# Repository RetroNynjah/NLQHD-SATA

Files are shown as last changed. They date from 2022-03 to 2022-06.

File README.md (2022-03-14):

# RetroNinja NLQHD-SATA
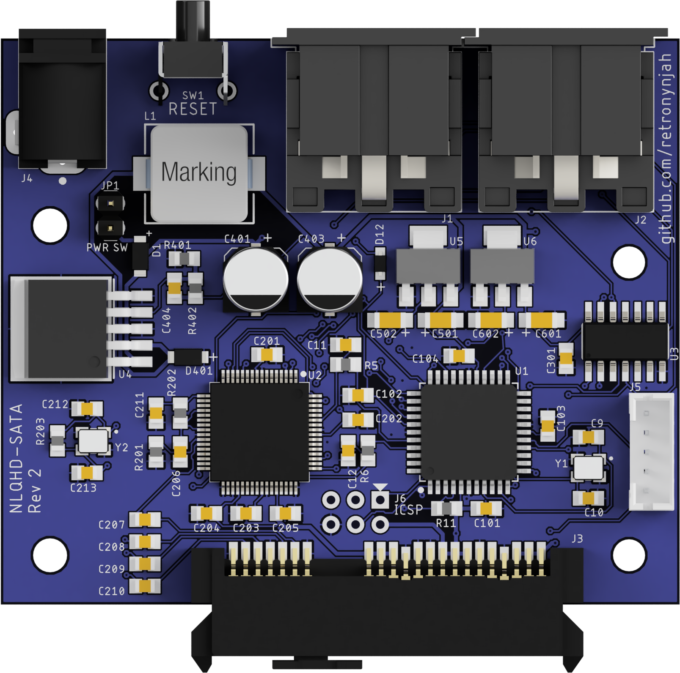
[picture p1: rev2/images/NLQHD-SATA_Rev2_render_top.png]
Render top
<br/>

A SATA-disk interface for the Commodore IEC-bus based on the NLQHD-lite design by Jochen Adler a.k.a. NLQ. The original design, documentation, firmware and source code can be found at [nlq.de](http://nlq.de).

## NLQ-HD
The NLQHD disk interface is a JiffyDOS compatible hard disk controller for the IEC bus. It was designed by Jochen Adler who also wrote the firmware. It supports a partition size of up to 128GB. Larger hard drives can be used but the partition size can not be greater than 128GB. 
The file system used is FAT32 so with a SATA-USB adapter it's easy to unplug and connect the SATA drive to a computer for quick file transfers.  
It should work with all Commodore 8-bit computers using an IEC bus. The drive can in theory be used with a stock kernal in the computer but the standard commands for navigating directories uses the command channel and are pretty cumbersome to use. A JiffyDOS kernal or one of it's derivatives such as S-JiffyDOS or JaffyDOS is pretty much required.

## NLQHD-SATA
This SATA version is a somewhat simplified design in that it doesn't have the same level of over-voltage protection as the original design has. The reason is that I wanted to keep the size of the design down (70x58mm) to fit in a 3D-printed enclosure. It also can't be powered by 1541-II PSU so the protection is less necessary than on the original design. I recommend that this version is powered using a decent quality 12V DC adapter with a center positive barrel connector.  
I have also removed the debugging/programming dip switches so the programming software for the C64 can't be used for flashing the firmware. I don't think it's safe to use so don't even try to use it!  
Instead I have added an ICSP programming header so that the firmware can be programmed in circuit using any AVR programmer such as AVR-ISP, USBASP or even an Arduino (Arduino as ISP). More importantly I've also added a JMH330 PATA-SATA bridge so that the interface can be used with more available and reliable SSD drives without an extra adapter. All SATA drives should be possible to use, from older 3.5" rotational drives to the newer 2.5" SSD drives. 
I replaced the sometimes hard-to-find 5 Volt regulator with integrated components based around an LM2596 voltage regulator. These have unfortunately also became harder to find from reliable sources at the time of writing but are easy to find on eBay or AliExpress. 3.3V and 1.8V voltage regulators have been added to drive the SATA bridge.  
I have made a separate front panel for the control buttons and LEDs. It connects to the mainboard using a 5 pin connector and can easily be replaced by a different panel if you need a different shape.  

<br/>
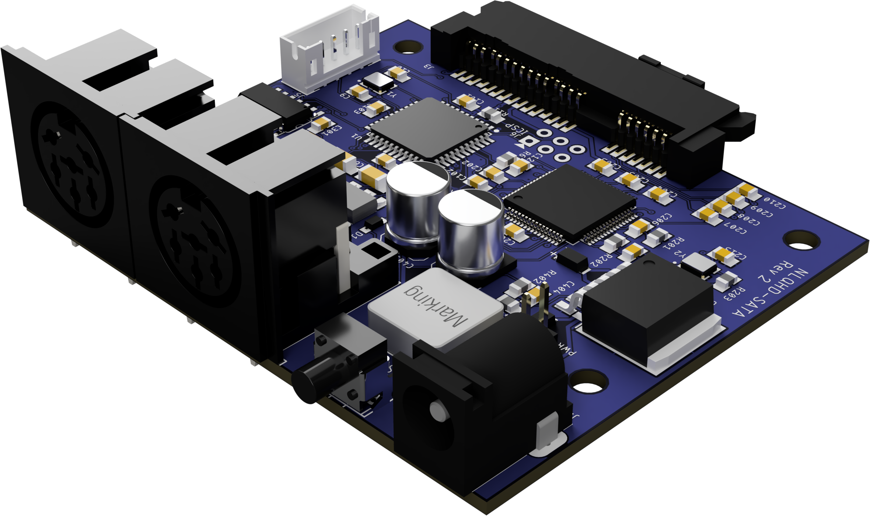
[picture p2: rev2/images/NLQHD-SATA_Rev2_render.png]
Render top
<br/>

I have also created a simple front panel board with buttons and status LEDs.  
This separate board should be pretty easy to modify to suite your own needs.
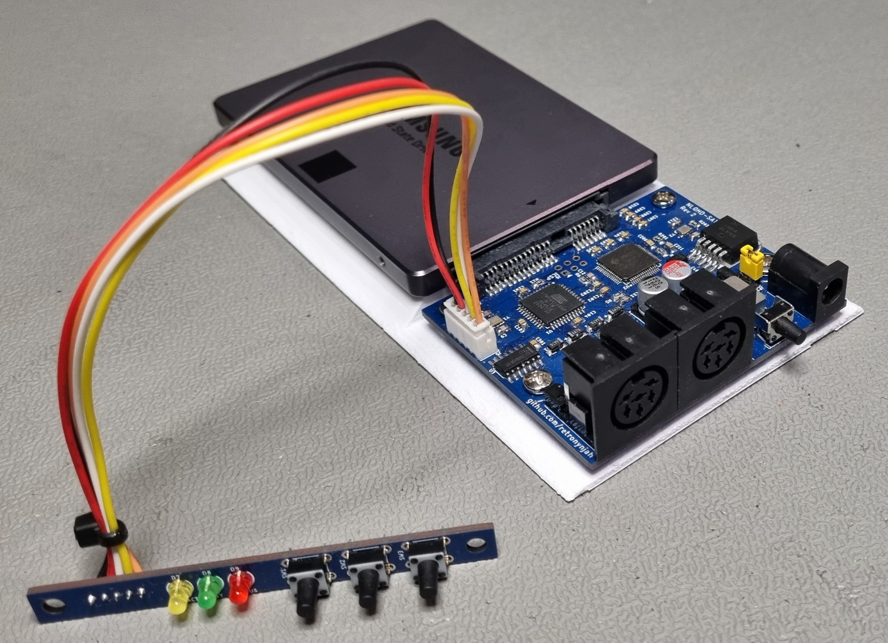
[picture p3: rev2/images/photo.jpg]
<br/>

## Mainboard BOM

|Parts|Device|Value|Qty|
|-----|-----|-----|-----|
|C101, C102, C103, C104, C201, C202, C203, C204, C205, C206, C301|Ceramic capacitor 0805|100n|11|
|C11, C12|Ceramic capacitor 0805|100p|2|
|C207, C208, C209, C210|Ceramic capacitor 0805|10n|4|
|C211|Ceramic capacitor 0805|1u 10V|1|
|C401|Electrolytic capacitor SMD 6.3X7.7|100u 25V|1|
|C403|Electrolytic capacitor SMD 6.3X7.7|220u 10V|1|
|C404|Ceramic capacitor 0805|10n(*)|1|
|C501, C502, C601, C602|Polarized tantalum capacitor 1206|10uF 10V|4|
|C9, C10, C212, C213|Ceramic capacitor 0805|22p|4|
|D1, D401|Schottky diode 3A SOD-123FL|S34|2|
|D12|General purpose diode SOD-323F|1N4148WSF|1|
|J1, J2|DIN-6 Female PCB-mount||2|
|J3|Molex 22-pin SATA host connector|0470184000|1|
|J4|DC Barrel Jack|PJ-002A|1|
|J5|Shrouded male JST header|5-pin, 2.0mm|1|
|J6|Pin header|2x3-pin, 2.54mm|1|
|JP1|Jumper or power switch|2-pin, 2.54mm|1|
|L1|Inductor 10x11mm|33uH|1|
|R11|Resistor 0805|10k|1|
|R201|Resistor 0805|12k|1|
|R202|Resistor 0805|47k|1|
|R203|Resistor 0805|1M|1|
|R401|Resistor 0805|1k (*)|1|
|R402|Resistor 0805|3k1/0R(*)|1|
|R5, R6|Resistor 0805|100R|2|
|SW1|Tact. switch right angle|6.0x5.0x8.5mm|1|
|U1|Microcontroller TQFP-44|ATmega1284(P)|1|
|U2|PATA-SATA bridge TQFP-64|JMH330|1|
|U3|Hex buffers/drivers SOIC14|74LS07|1|
|U4|Switching regulator TO263-5|LM2596 (AP1501A)|1|
|U5|Volt regulator 3.3V SOT-223|LD1117-3.3|1|
|U6|Volt regulator 1.8V SOT-223|LD1117-1.8|1|
|Y1|Crystal ECX-32|8MHz|1|
|Y2|Crystal ECX-32|25MHz|1|

(*) Only for Adjustable LM2596.
If using a fixed 5V LM2596: Do NOT install R401 and C404 and use a 0 Ohm resistor at R402

There are several variants of 6-pin DIN connectors with different foot prints. I have tried to accommodate them all in one single foot print. Let me know if you have a DIN connector that still doesn't fit this board.

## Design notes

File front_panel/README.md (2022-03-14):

A front panel for the NLQHD-SATA

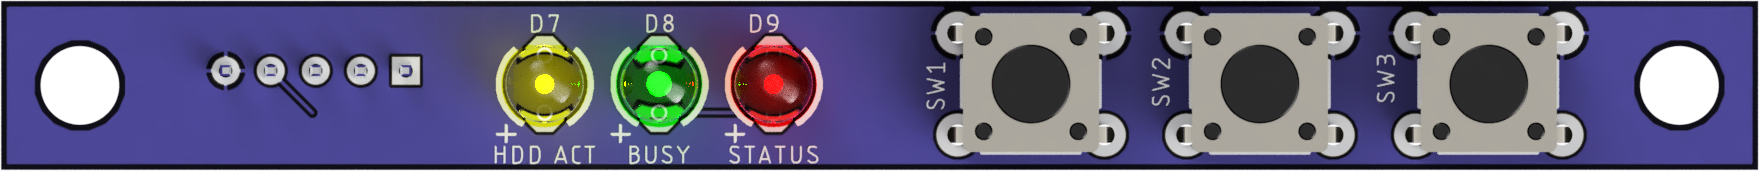
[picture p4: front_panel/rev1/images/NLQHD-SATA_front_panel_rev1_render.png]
Render
<br/>

## BOM
|Parts|Device|Value|Qty|
|-----|-----|-----|-----|
|SW2, SW3|Tact switch|6.0x6.0x9.0mm|2|
|D7|3mm LED|Yellow|1|
|D8|3mm LED|Green|1|
|D9|3mm LED|Red|1|
|D2, D3|General purpose diode SOD-323F|1N4148WSF|2|
|R7, R8, R9|Resistor 0805|560R|3|

Choose resistors that work with the actual LEDs you have on hand. Many super bright LEDs need a lot more resistance to not be blindingly bright.

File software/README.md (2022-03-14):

This folder contains is the original software, firmware and sourece code created by Jochen Adler (NLQ). All rights belongs to him.  
The same package is available from http://nlq.de. I'm only keeping a copy here for convenience.

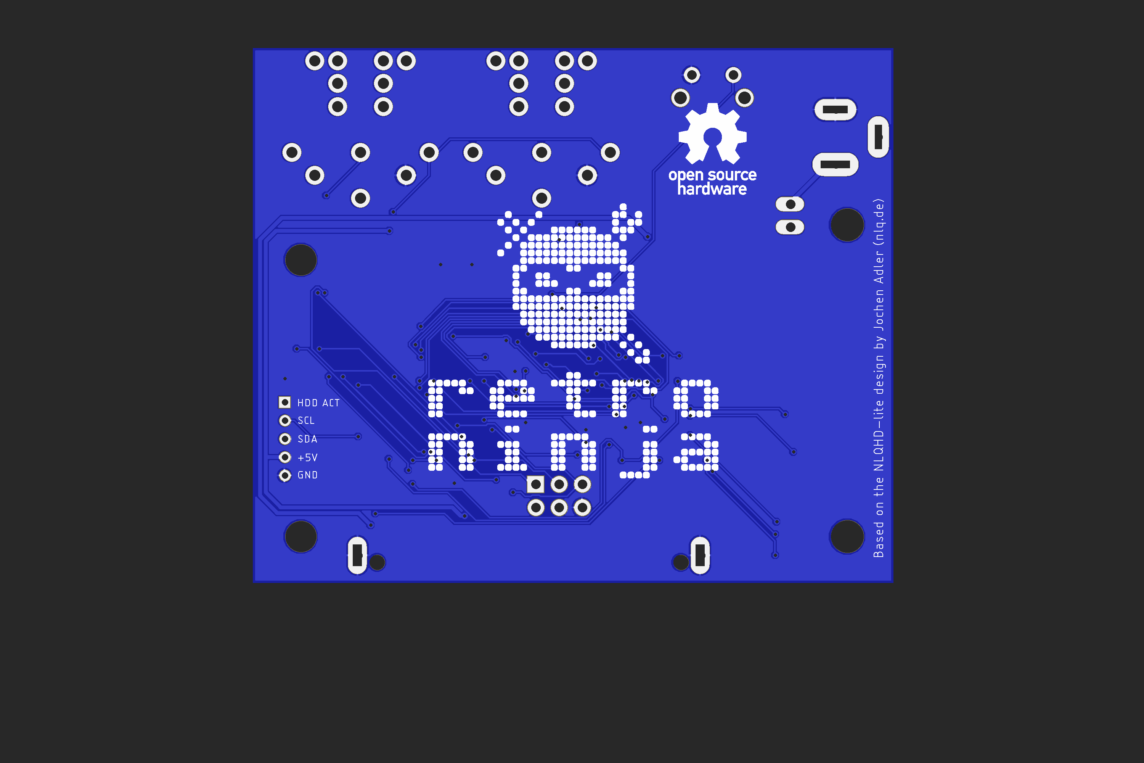
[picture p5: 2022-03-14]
rev2/images/NLQHD-SATA Rev 2 pcb bottom.png

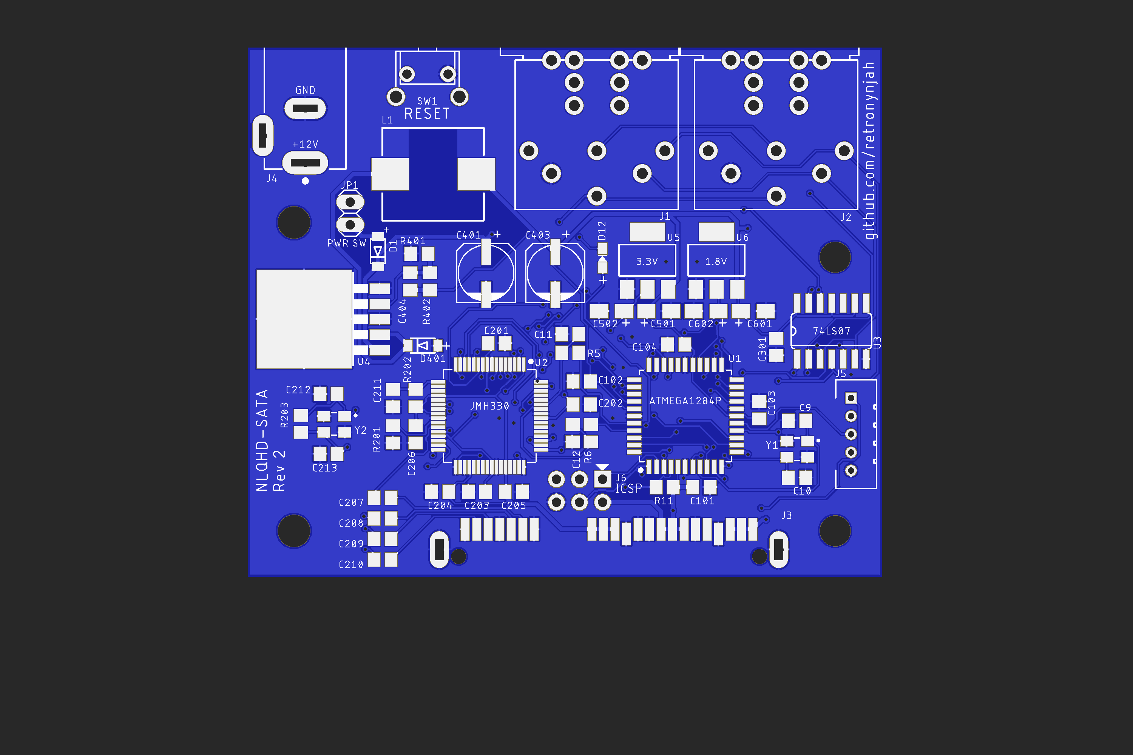
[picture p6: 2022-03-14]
rev2/images/NLQHD-SATA Rev 2 pcb top.png

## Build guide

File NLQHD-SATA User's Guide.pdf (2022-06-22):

# NLQHD-SATA

# User's Guide

### Version 1.1

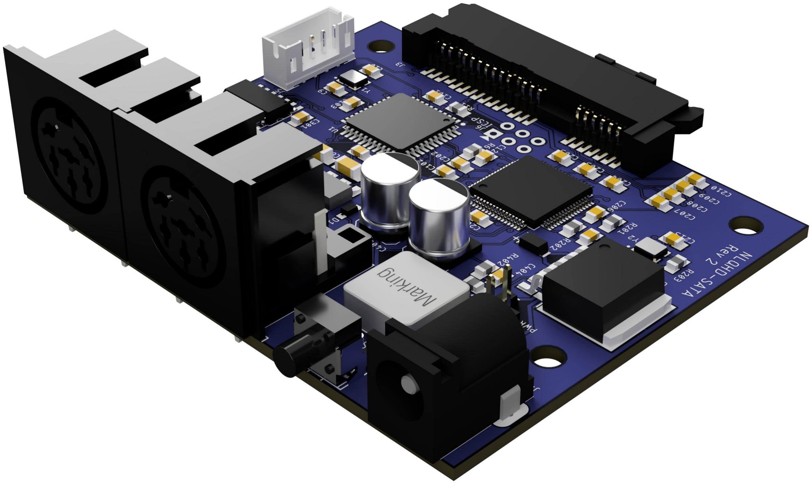
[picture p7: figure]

## Table of Contents

## Getting started

## Assembly

I suggest that you start the build by adding the LM2596 regulator and all it's peripheral components (see the area around the LM2596 in the schematic) and verify that you can power the PCB with 12V and get 5V out from the regulator. If you make a mistake here there's a good chance that the regulator outputs 12V and that would fry other components on the board if they were installed. You should have 5V on both sides of the inductor L1 when everything is right.
Because of component shortages ,the PCB is made to support a couple of different 5V regulators – a fixed 5V LM2596 regulator or the cheaper adjustable LM2596 which requires a couple of extra peripheral components (R401 and C404) and a 3.1kΩ resistor at R402 to keep the voltage at 5V.
If you go with a fixed 5V regulator your should not mount R401 and C404 and you should install a 0Ω resistor or a little jumper wire instead of a resistor at R402.
When you have an acceptable 5V output, add the 3.3V and 1.8V regulators and capacitors C501, C502, C601, C602 and verify the 1.8V and 3.3V by measuring the center pin on each regulator.
When all voltages are verified you can add the rest of the SMD parts including the SATA connector and then the through-hole parts.

### Supplying power

The controller needs to be powered by 12V DC through a barrel jack with +12V on the center pin or by soldering wires to the foot print where the barrel jack would be.
For SSD drives, a 1A power supply should be more than enough but it might be a bit on the low side for a 3.5" 7200 RPM disk so a 2A PSU might be a safer choice in that case.
The jumper JP1 can be used to install a power switch, a header and jumper or a permanent solder jumper. Opening the jumper removes all power to the board.

## Flashing the firmware

The firmware to program the ATmega with is named nh4lite0.bin and can be found in the ajnnh057.zip archive under software in the NLQHD-SATA GitHub repository at https://github.com/RetroNynjah/NLQHD-SATA (https://github.com/RetroNynjah/NLQHD-SATA) or at http://nlq.de
The following AVR fuses should be used.
LFUSE | $FF
HFUSE | $D9
EFUSE | $FD

There are several ways to program an ATmega but the below example is using AVRDUDE.
Setting the fuses and flashing the firmware on an Atmega1284 at the same time can be done like this.

You will have to adjust the command to match your programmer and change your AVR device if you are using an Atmega1284P. The fuses are the same for 1284P.

avrdude -C avrdude.conf -v -p atmega1284 -c usbasp -U lfuse:w:0xff:m -U hfuse:w:0xd9:m -U efuse:w:0xfd:m -Uflash:w:nh4lite0.bin

## Configuring the interface

The device configuration is stored in the EEPROM of the ATmega1284 and needs to be set after programming the firmware. To configure the device, connect it to a C64 or C128 and run the configuration program.
The configuration program can be found on the nlqhd-057-lite.d64 and nlqhd-057-lite.d81 disks.
The program is called C-NLQ-CAL&CON271
When asked if you are using NLQHD-lite hardware the answer is Yes.
Go through the configuration wizard and choose to configure each option. The default choices are usually fine but you may want to select a device ID that suits your environment.
When you are back at the configuration menu, select M to copy messages to the Atmega1284 EEPROM. This transfer status message texts and drive identification string to the EEPROM. Without this the drive will not report any text along with the error codes when querying the drive error channel for status and it won't present itself properly if you query the error channel directly after drive reset. You can use the @ command to query the drive error channel from JiffyDOS to make sure that it's reporting status correctly.
You don't need to run any calibration with the NLQHD-SATA because it is using an external crystal and therefore it's also not a problem to use JiffyDOS while configuring the device despite the warnings in the configuration program that speeders should be disabled until the oscillator has been calibrated.

## Formatting the disk

You can use the program C-NLQ-PAR&FOR232 to partition and format your disk using FAT32 if it's not already partitioned and formatted. Using this tool for partitioning a larger disk ensures that the partition size is exactly the maximum supported size.

## Using your hard drive

## Disk commands

The below command examples assumes JiffyDOS kernal on the computer.
To issue the commands without JiffyDOS you would have to use a command like OPEN15,8,15,”CD:GAMES” instead of just @CD:GAMES.

### Changing directories

Move to directory

Go up one directory level

Go back to the root directory

All commands that target file or folder names that includes spaces must be within quotes. Examples:
Move to directory

### Adding and removing files and directories

Create new directory

Remove directory (must be empty)

Delete (scratch) a file

Delete (scratch) all files in current directory with names beginning with MY

Delete (scratch) all files in current directory

@CD:GAMES

@CD//

@CD<= (PETSCII left arrow)

@”CD:MY GAMES”

@”RD:MY OLD DIR”

@”S:MY OLD FILE”

@”S:MY*”

@S:*

@”MD:MY APPS”

### Renaming files and directories

Rename a file or directory

### Misc commands

Turn off device (press reset switch to wake up again)

## Other functions

### Swapping ID

It's possible to temporarily swap device ID with another device that has device ID 8 or 9.
This makes it possible to run software that assumes that a disk drive must have ID 8 or 9.
To swap ID, press the middle button (left button if there are only two buttons) eight times. The busy light will start flashing series of eight flashes. Now press the right button to execute the device change.
Pressing the middle button nine times followed by a right button press swaps ID with device 9.
Example: The NLQHD is device 30 and a 1541 disk drive is device 8. After the ID swap the 1541 is device 30 and the NLQHD is device 8.
The NLQHD can now be used as if the current folder was a disk inserted into device 8.

### Standby mode

The device can be put into standby by holding the right button for 4 seconds or more. When the device is in standby it's device ID is removed from the IEC bus and can be used by other devices.
To wake the device from standby you can press the middle button on the front panel or the reset button at the back of the interface.

## Resources

NLQHD-SATA GitHub repository https://github.com/RetroNynjah/NLQHD-SATA NLQ web site
http://nlq.de
JiffyDOS web site
http://www.jiffydos.com

@”R:NEW FILENAME=OLD FILENAME”

@AOF

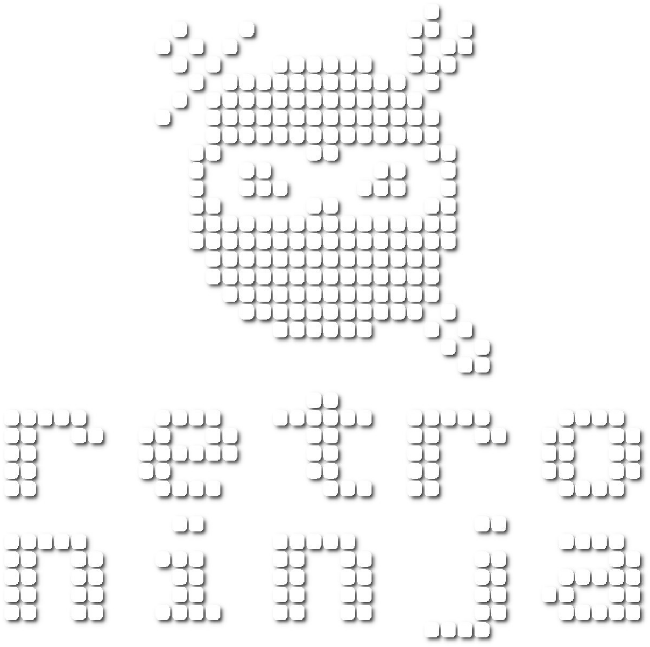
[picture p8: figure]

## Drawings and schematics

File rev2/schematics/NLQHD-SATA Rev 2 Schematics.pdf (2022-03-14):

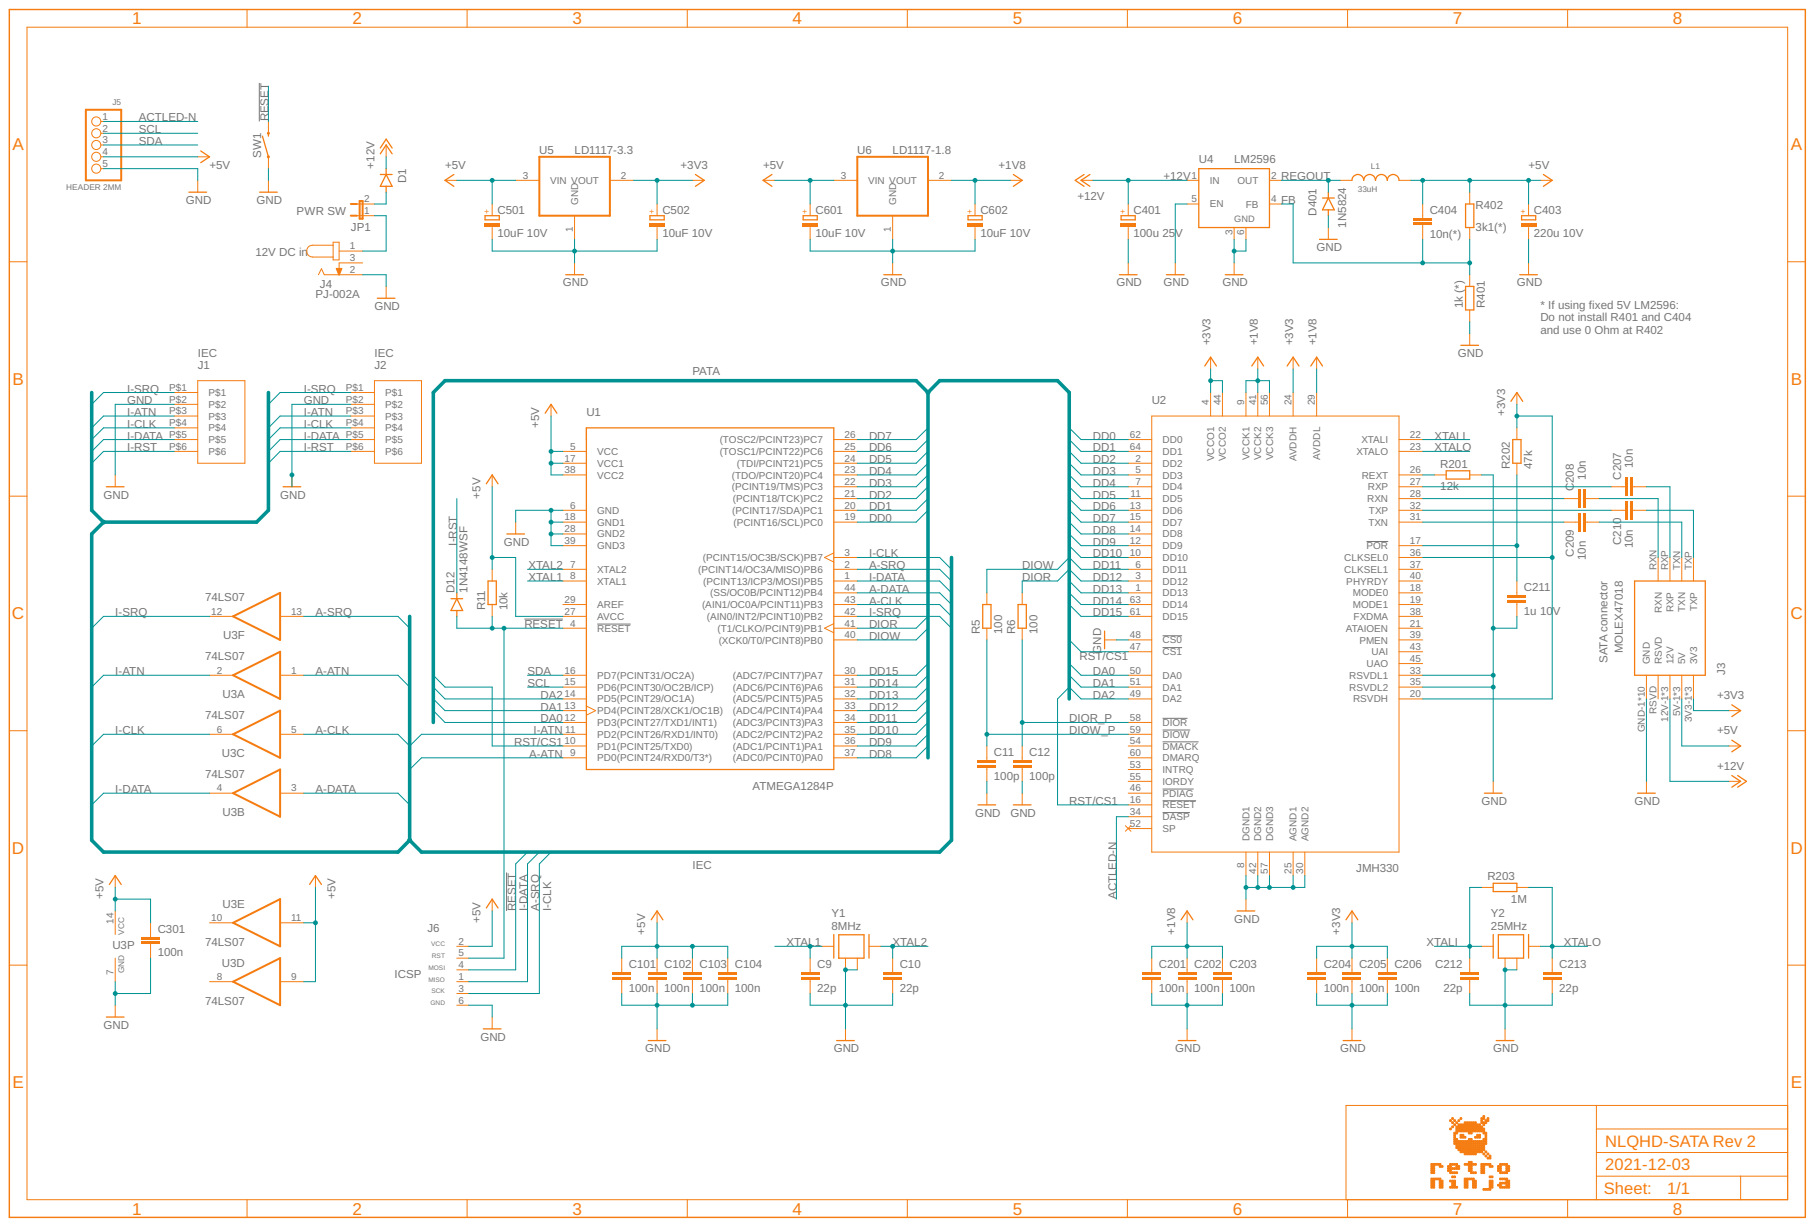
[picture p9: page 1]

* If using fixed 5V LM2596: Do not install R401 and C404

and use 0 Ohm at R402

SCK RST VCC MOSI GND

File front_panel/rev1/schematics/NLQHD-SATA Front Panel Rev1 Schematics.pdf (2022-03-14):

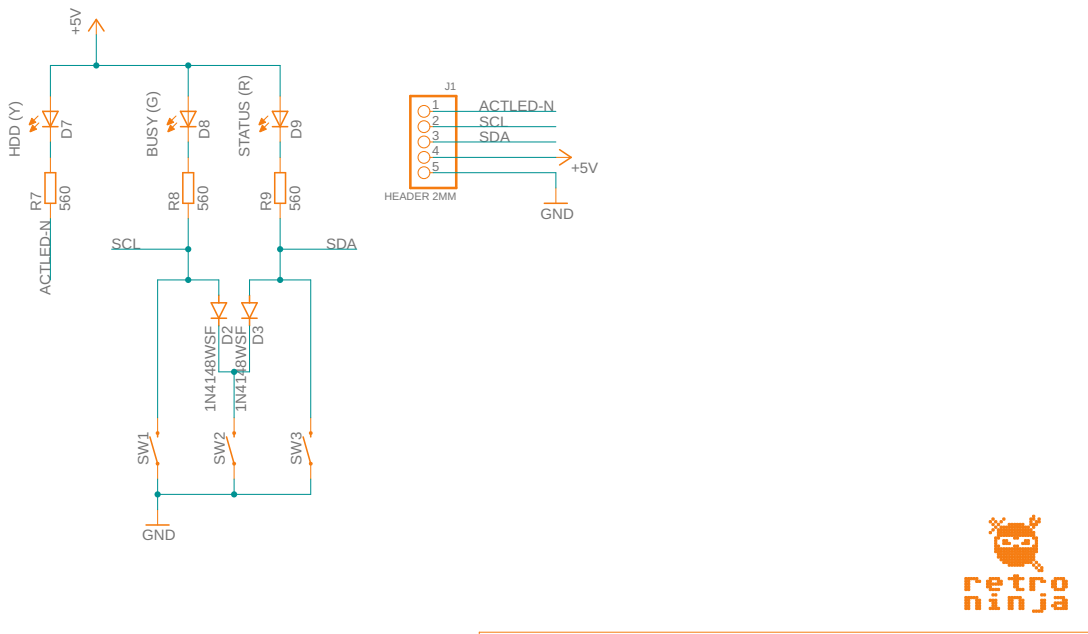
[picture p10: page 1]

NLQHD-SATA Front Panel Rev 1

Document Number: | REV: 1

Date: 2021-12-07 | Sheet: 1/1

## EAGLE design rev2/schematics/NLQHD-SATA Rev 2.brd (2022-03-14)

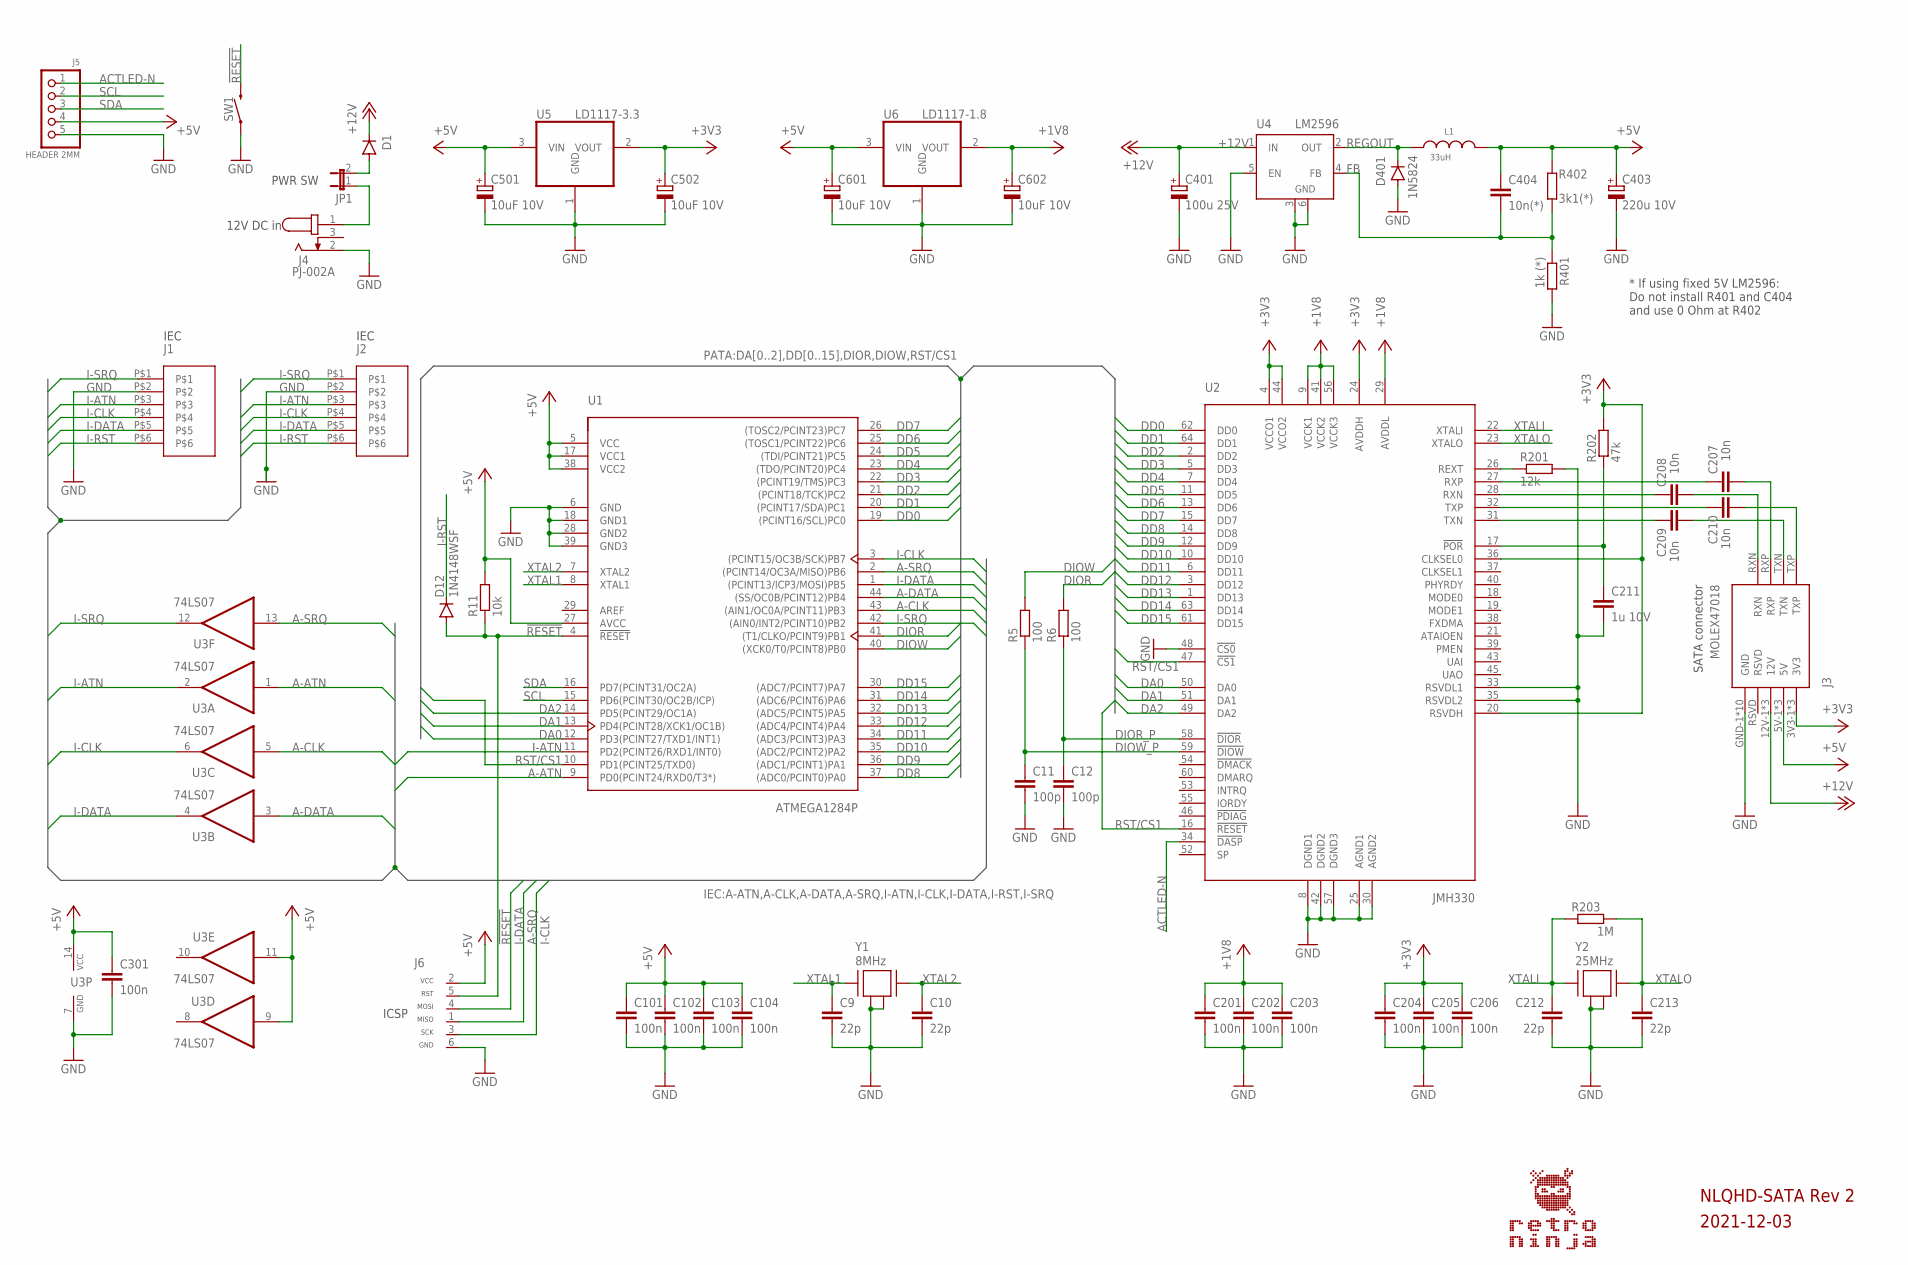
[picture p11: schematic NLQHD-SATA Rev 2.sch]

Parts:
C9, C10, C212, C213: 22p; C0805
C11, C12: 100p; C0805
C101, C102, C103, C104, C201, C202, C203, C204, C205, C206, C301: 100n; C0805
C207, C208, C209, C210: 10n; C0805
C211: 1u 10V; C0805
C401: 100u 25V; CAP_POL_SMD_6.3X7.7
C403: 220u 10V; CAP_POL_SMD_6.3X7.7
C404: 10n(*); C0805
C501, C502, C601, C602: 10uF 10V; A/3216-18R
D1: DIODE_SOD-123FL; SOD-123FL
D12: 1N4148WSF; SOD-323F
D401: 1N5824; SOD-123FL
J1, J2: DIN-6_PCB; DIN-6-PCB
J3: MOLEX47018; MOLEX47018SATA
J4: PJ-002A; CUI_PJ-002A
J5: HEADER 2MM; HEADER_1X5_2MM_JST
J6: ICSP_CONNECTOR_6_ALT; HEADER_2X3_ALT
JP1: JUMPER-2; HEADER_1X2
L1: 33uH; WE-LHMI_1040
R5, R6: 100; R0805
R11: 10k; R0805
R201: 12k; R0805
R202: 47k; R0805
R203: 1M; R0805
R401: 1k (*); R0805
R402: 3k1(*); R0805
SW1: SWITCH_MOMENTARY_6.0X5.0_RIGHT_ANGLE; SWITCH_MOM_6.0MMX5.0MM_RIGHT_ANGLE
U1: ATMEGA1284P; TQFP-44
U2: JMH330; TQFP-64_12X12X1.20
U3: 74LS07; SOIC14
U4: LM2596; TO263-5
U5: LD1117-3.3; SOT223
U6: LD1117-1.8; SOT223
Y1: 8MHz; ECX-32
Y2: 25MHz; ECX-32

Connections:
!POR: C211.1, R202.1, U2.17 (!POR)
!RESET: D12.A, J6.5 (RST), R11.1, SW1.2, U1.4 (!RESET)
+1V8: C201.1, C202.1, C203.1, C602.+, U2.9 (VCCK1), U2.29 (AVDDL), U2.41 (VCCK2), U2.56 (VCCK3), U6.2 (VOUT)
+3V3: C204.1, C205.1, C206.1, C502.+, J3.3V3-1 (3V3), J3.3V3-2 (3V3), J3.3V3-3 (3V3), R202.2, U2.4 (VCCO1), U2.20 (RSVDH), U2.24 (AVDDH), U2.36 (CLKSEL0), U2.44 (VCCO2), U5.2 (VOUT)
+5V: C101.1, C102.1, C103.1, C104.1, C301.1, C403.+, C404.1, C501.+, C601.+, J3.5V-1 (5V), J3.5V-2 (5V), J3.5V-3 (5V), J5.4, J6.2 (VCC), L1.2, R11.2, R402.2, U1.5 (VCC), U1.17 (VCC1), U1.27 (AVCC), U1.38 (VCC2), U3.9 (I), U3.11 (I), U3.14 (VCC), U5.3 (VIN), U6.3 (VIN)
+12V: C401.+, D1.C, J3.12V-1 (12V), J3.12V-2 (12V), J3.12V-3 (12V), U4.1 (IN)
+12V-IN: J4.1, JP1.1
A-ATN: U1.9 (PD0(PCINT24/RXD0/T3*)), U3.1 (I)
A-CLK: U1.43 ((AIN1/OC0A/PCINT11)PB3), U3.5 (I)
A-DATA: U1.44 ((SS/OC0B/PCINT12)PB4), U3.3 (I)
A-SRQ: J6.1 (MISO), U1.2 ((PCINT14/OC3A/MISO)PB6), U3.13 (I)
ACTLED-N: J5.1, U2.34 (!DASP)
DA0: U1.12 (PD3(PCINT27/TXD1/INT1)), U2.50 (DA0)
DA1: U1.13 (PD4(PCINT28/XCK1/OC1B)), U2.51 (DA1)
DA2: U1.14 (PD5(PCINT29/OC1A)), U2.49 (DA2)
DD0: U1.19 ((PCINT16/SCL)PC0), U2.62 (DD0)
DD1: U1.20 ((PCINT17/SDA)PC1), U2.64 (DD1)
DD2: U1.21 ((PCINT18/TCK)PC2), U2.2 (DD2)
DD3: U1.22 ((PCINT19/TMS)PC3), U2.5 (DD3)
DD4: U1.23 ((TDO/PCINT20)PC4), U2.7 (DD4)
DD5: U1.24 ((TDI/PCINT21)PC5), U2.11 (DD5)
DD6: U1.25 ((TOSC1/PCINT22)PC6), U2.13 (DD6)
DD7: U1.26 ((TOSC2/PCINT23)PC7), U2.15 (DD7)
DD8: U1.37 ((ADC0/PCINT0)PA0), U2.14 (DD8)
DD9: U1.36 ((ADC1/PCINT1)PA1), U2.12 (DD9)
DD10: U1.35 ((ADC2/PCINT2)PA2), U2.10 (DD10)
DD11: U1.34 ((ADC3/PCINT3)PA3), U2.6 (DD11)
DD12: U1.33 ((ADC4/PCINT4)PA4), U2.3 (DD12)
DD13: U1.32 ((ADC5/PCINT5)PA5), U2.1 (DD13)
DD14: U1.31 ((ADC6/PCINT6)PA6), U2.63 (DD14)
DD15: U1.30 ((ADC7/PCINT7)PA7), U2.61 (DD15)
DIOR: R6.2, U1.41 ((T1/CLKO/PCINT9)PB1)
DIOR_P: C12.1, R6.1, U2.58 (!DIOR)
DIOW: R5.2, U1.40 ((XCK0/T0/PCINT8)PB0)
DIOW_P: C11.1, R5.1, U2.59 (!DIOW)
FB: C404.2, R401.1, R402.1, U4.4 (FB)
GND: C9.2, C10.2, C11.2, C12.2, C101.2, C102.2, C103.2, C104.2, C201.2, C202.2, C203.2, C204.2, C205.2, C206.2, C211.2, C212.2, C213.2, C301.2, C401.-, C403.-, C501.-, C502.-, C601.-, C602.-, D401.A, J1.P$2, J2.P$2, J3.GND-1 (GND), J3.GND-2 (GND), J3.GND-3 (GND), J3.GND-4 (GND), J3.GND-5 (GND), J3.GND-6 (GND), J3.GND-7 (GND), J3.GND-8 (GND), J3.GND-9 (GND), J3.GND-10 (GND), J4.2, J5.5, J6.6 (GND), R201.2, R401.2, SW1.1, U1.6 (GND), U1.18 (GND1), U1.28 (GND2), U1.39 (GND3), U2.8 (DGND1), U2.25 (AGND1), U2.30 (AGND2), U2.33 (RSVDL1), U2.35 (RSVDL2), U2.42 (DGND2), U2.48 (!CS0), U2.57 (DGND3), U3.7 (GND), U4.3 (GND), U4.5 (EN), U4.6 (GND), U5.1 (GND), U6.1 (GND), Y1.2, Y1.4, Y2.2, Y2.4
I-ATN: J1.P$3, J2.P$3, U1.11 (PD2(PCINT26/RXD1/INT0)), U3.2 (O)
I-CLK: J1.P$4, J2.P$4, J6.3 (SCK), U1.3 ((PCINT15/OC3B/SCK)PB7), U3.6 (O)
I-DATA: J1.P$5, J2.P$5, J6.4 (MOSI), U1.1 ((PCINT13/ICP3/MOSI)PB5), U3.4 (O)
I-RST: D12.C, J1.P$6, J2.P$6
I-SRQ: J1.P$1, J2.P$1, U1.42 ((AIN0/INT2/PCINT10)PB2), U3.12 (O)
unnamed: R201.1, U2.26 (REXT)
unnamed: D1.A, JP1.2
unnamed: C207.2, J3.RXP
unnamed: C208.2, J3.RXN
unnamed: C210.2, J3.TXP
unnamed: C209.2, J3.TXN
unnamed: C208.1, U2.28 (RXN)
unnamed: C209.1, U2.31 (TXN)
unnamed: C210.1, U2.32 (TXP)
unnamed: C207.1, U2.27 (RXP)
REGOUT: D401.C, L1.1, U4.2 (OUT)
RST/CS1: U1.10 (PD1(PCINT25/TXD0)), U2.16 (!RESET), U2.47 (!CS1)
SCL: J5.2, U1.15 (PD6(PCINT30/OC2B/ICP))
SDA: J5.3, U1.16 (PD7(PCINT31/OC2A))
XTAL1: C9.1, U1.8 (XTAL1), Y1.1
XTAL2: C10.1, U1.7 (XTAL2), Y1.3
XTALI: C212.1, R203.1, U2.22 (XTALI), Y2.1
XTALO: C213.1, R203.2, U2.23 (XTALO), Y2.3

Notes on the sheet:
SATA connector
12V DC in
IEC
PWR SW
ICSP
2021-12-03
* If using fixed 5V LM2596: Do not install R401 and C404 and use 0 Ohm at R402
NLQHD-SATA Rev 2

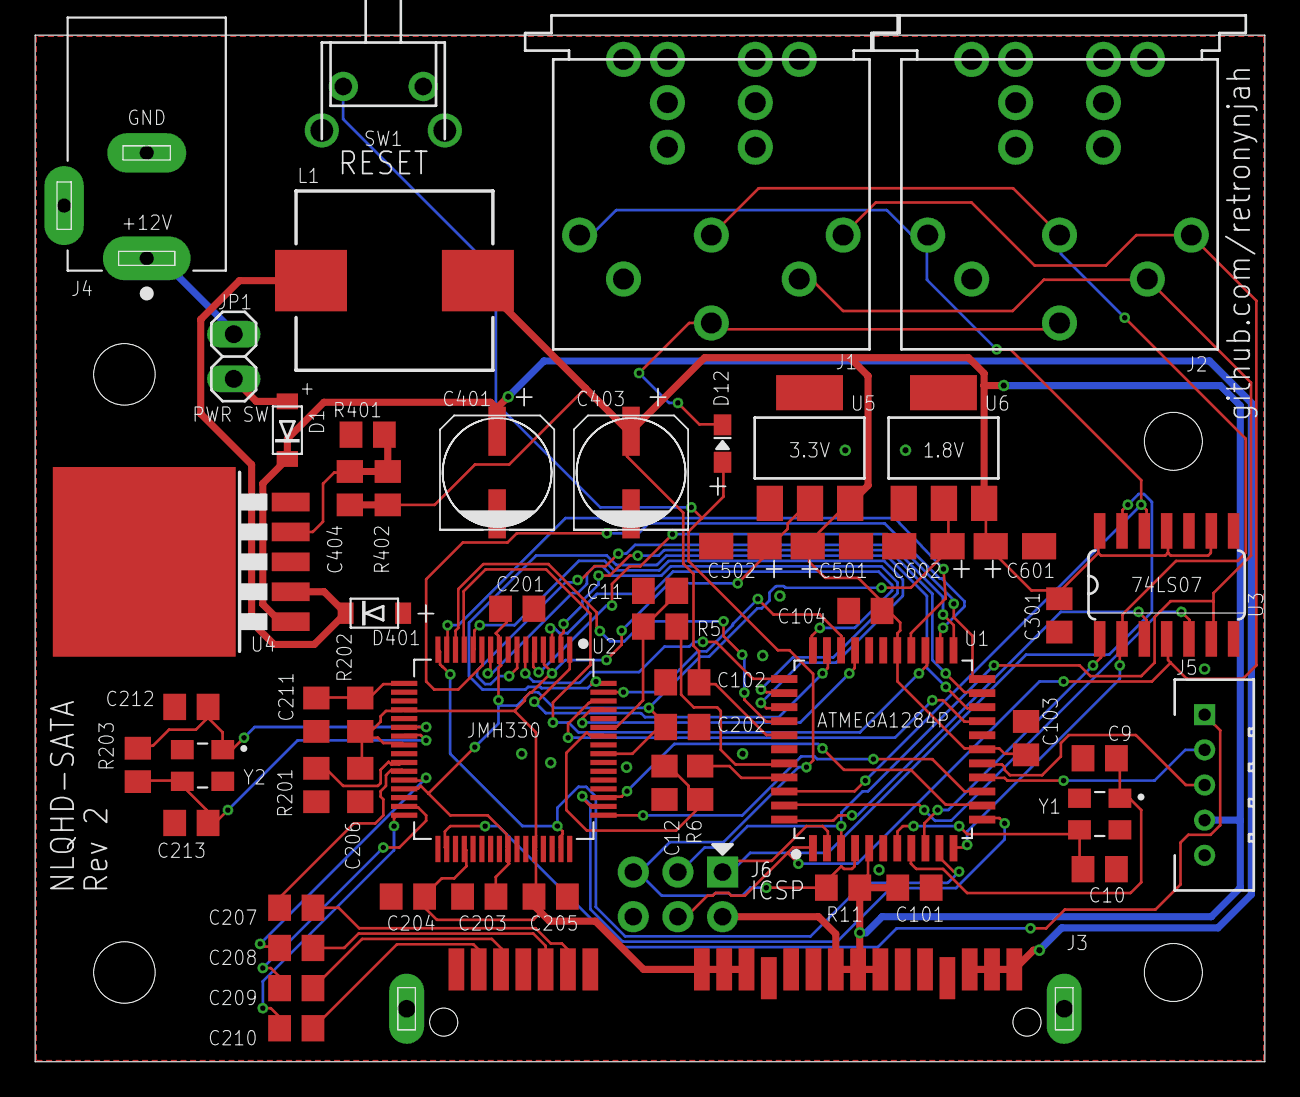
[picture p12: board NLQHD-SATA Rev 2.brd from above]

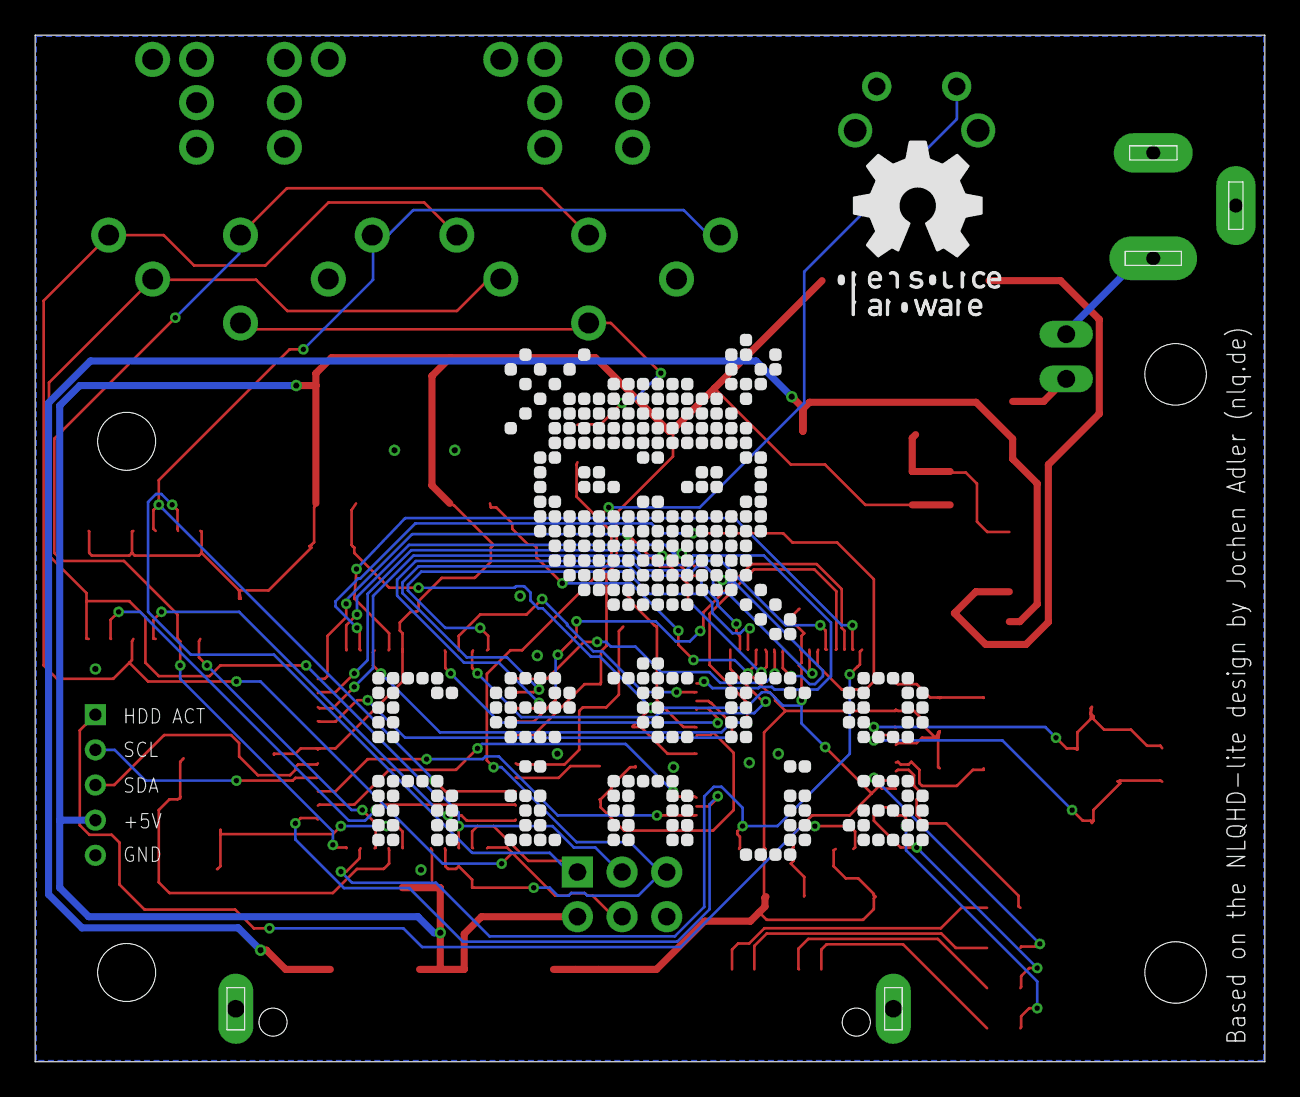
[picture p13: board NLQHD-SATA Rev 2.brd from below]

Board: 2 copper layers, 70.0 x 58.4 mm, 59 parts (2 on the bottom side), 60 nets.

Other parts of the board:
U$1: RETRONINJA_30MM
U$2: OSHW_10MM

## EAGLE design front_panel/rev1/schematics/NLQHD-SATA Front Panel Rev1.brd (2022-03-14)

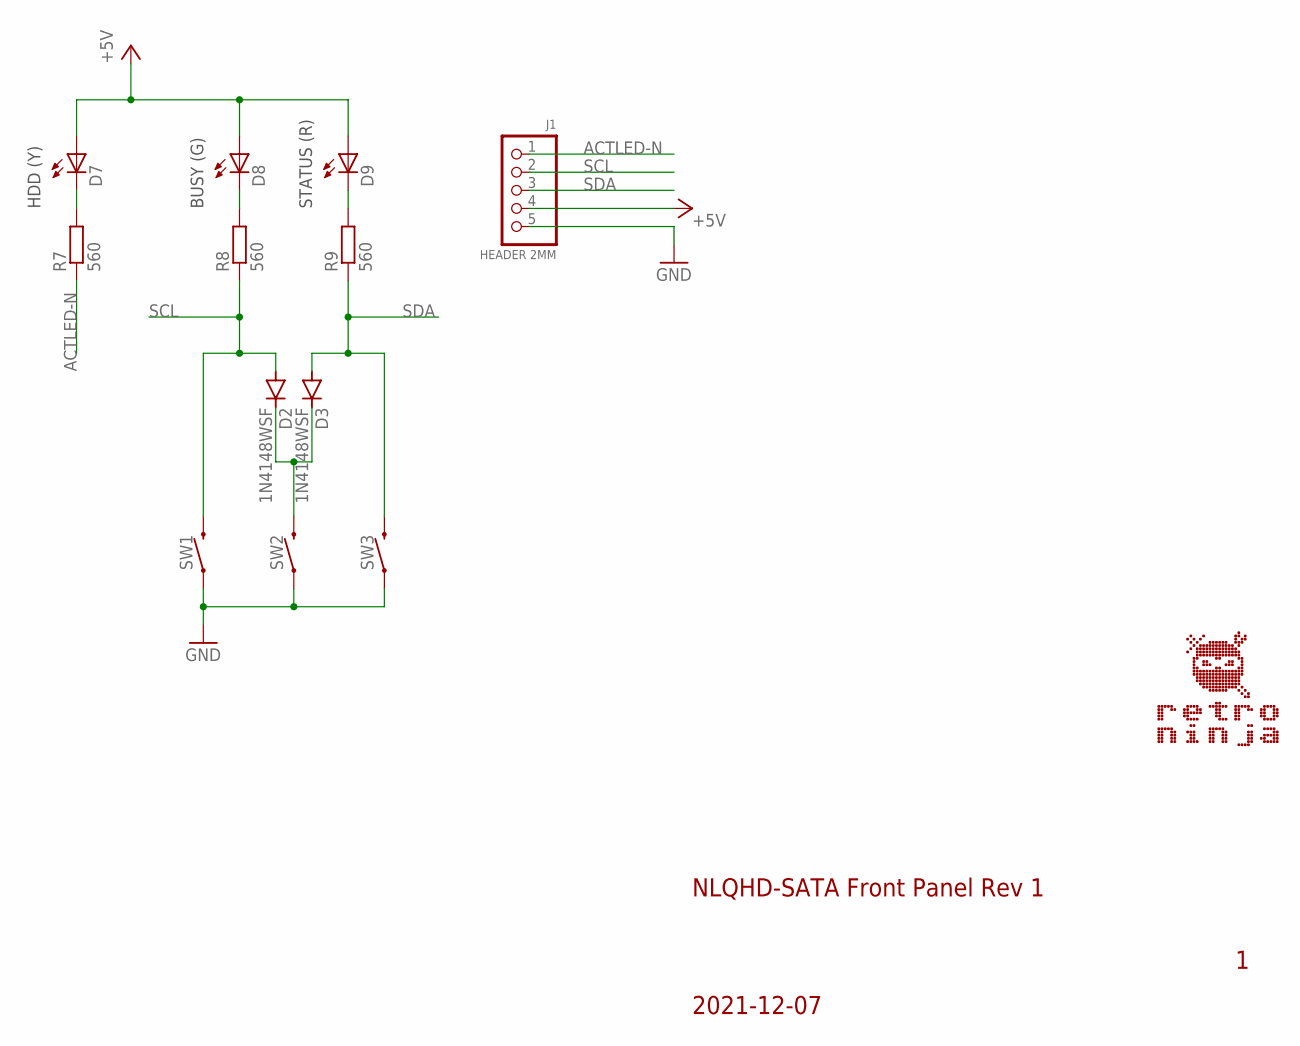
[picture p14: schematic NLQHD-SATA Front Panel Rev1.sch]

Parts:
D2, D3: 1N4148WSF; SOD-323F
D7: LED_3MM_RED; LED3MM_RED
D8, D9: LED_3MM_GREEN; LED3MM_GREEN
J1: HEADER 2MM; HEADER_1X5_2MM_JST
R7, R8, R9: 560; R0805
SW1, SW2, SW3: SWITCH_MOMENTARY_6.0X5.0; SWITCH_MOM_6.0MMX5.0MM

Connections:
+5V: D7.A, D8.A, D9.A, J1.4
ACTLED-N: J1.1, R7.1
ACTLED-RES: D7.K (C), R7.2
BUSYLED-RES: D8.K (C), R8.2
GND: J1.5, SW1.1, SW1.2 (1), SW2.1, SW2.2 (1), SW3.1, SW3.2 (1)
unnamed: D2.C, D3.C, SW2.3 (2), SW2.4 (2)
SCL: D2.A, J1.2, R8.1, SW1.3 (2), SW1.4 (2)
SDA: D3.A, J1.3, R9.1, SW3.3 (2), SW3.4 (2)
STATLED-RES: D9.K (C), R9.2

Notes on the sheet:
BUSY (G)
HDD (Y)
STATUS (R)
NLQHD-SATA Front Panel Rev 1
2021-12-07

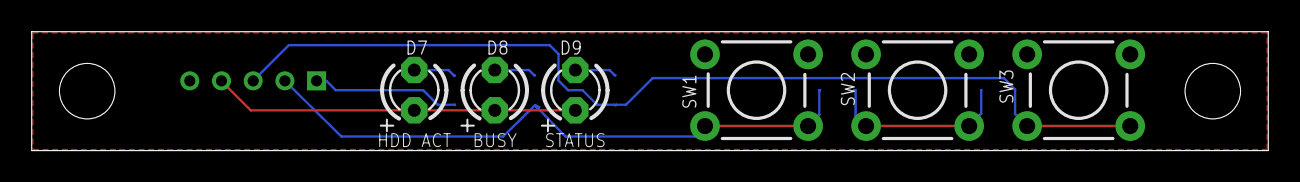
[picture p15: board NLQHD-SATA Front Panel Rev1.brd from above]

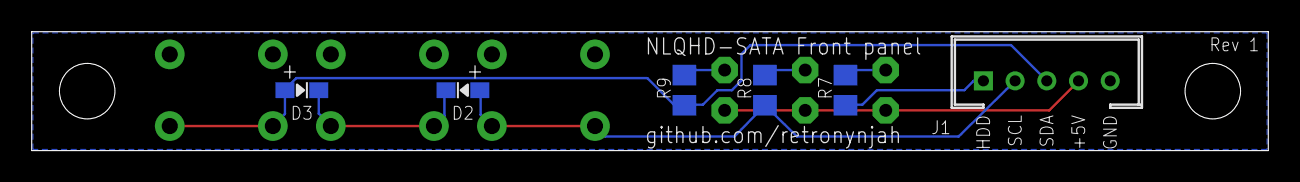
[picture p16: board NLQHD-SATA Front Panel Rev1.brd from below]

Board: 2 copper layers, 78.0 x 7.5 mm, 12 parts (6 on the bottom side), 9 nets.

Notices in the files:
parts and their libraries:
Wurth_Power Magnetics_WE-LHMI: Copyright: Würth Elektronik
